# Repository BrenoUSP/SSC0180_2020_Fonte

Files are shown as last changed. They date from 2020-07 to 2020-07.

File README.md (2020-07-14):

# Fonte de Tensão
  Projeto de uma fonte de tensão ajustável de 3 a 12 Volts com capacidade de 100 mA, desenvolvido pelo aluno Breno Lívio Silva de Almeida (número USP 10276675).

## Objetivo
  Irá se partir da tensão da tomada (220V ou 127V) que vai ter que ser transformada de 127V/220V em Corrente Alternada (C.A.) em uma tensão adequada para alimentar nosso circuito. Isto é, de 3V-12V em Corrente Contínua (C.C.).

## Desenvolvimento do trabalho

### Componentes
|Nome|Quantidade|Especificações|Explicações|Preço Unitário|
|---|---|---|---|---|
| **Fonte de alimentação** |**1**| **Energia da tomada**| Fonte de energia 127V | ----------- | 
| **Interruptor** |**1**| **250 V e 3 A**| Apenas para ligar e desligar o circuito | [R$28,89](https://produto.mercadolivre.com.br/MLB-1300399738-boto-chave-gangorra-mini-interruptor-liga-desliga-on-off-10x15mm-kcd13-101-3a-250v-arduino-_JM) | 
|**Transformador**|**1**| **bivolt, 15 V e 500 mA**  | Esse transformador foi escolhido visando garantir  uma margem de erro confortável para quedas de tensão nos componentes, além de ser bivolt, podendo lidar com 127V/220V|[R$44,89](https://produto.mercadolivre.com.br/MLB-1305497792-transformador-1515v-2a-trafo-bivolt-_JM) |
|**Ponte Retificadora**|**1**| **1000 V e 2 A** | Responsável por fazer a conversão correta de C.A. para C.C. | [R$3,07](https://produto.mercadolivre.com.br/MLB-1151520283-ponte-retificadora-2w10-2a-1000v-lote-com-10-pecas-_JM)|
|**Capacitor**|**1**| **330 μf/35 V** | Usado para estabilização da tensão do circuito, armazenando energia. O valor se chegou demonstrado pelos cálculos que vão ser explicados em seguida |[R$2,62](https://produto.mercadolivre.com.br/MLB-1475685583-20x-capacitor-eletrolitico-330uf35v-smd-105-10x102mm-_JM)|
|**Diodo Zener**|**1**| **13 V - 0,5 W** | Regula a tensão a 13 V |[R$0,32](https://produto.mercadolivre.com.br/MLB-1395521239-diodo-zener-13v-05w-1n5243-lote-de-100-pecas-_JM)|
|**Transistor**|**1**| **2N2222A ¹** | Atenua a corrente e a tensão. Corrente máxima no coletor de 0.8 mA e tensão máxima do coletor 75 V, mais que o suficiente para trabalhar com 25 V de entrada  |[R$1,05](https://produto.mercadolivre.com.br/MLB-1222136291-20-pecas-transistor-npn-2n2222a-_JM) |
|**Resistência**|**2**| **5,6K Ω** | R1 utilizado para limitar a tensão no zener de modo que está fique na faixa de 13V e o R3 se adapta ao potenciômetro mantendo a tensão de 3V a 12V  |[R$1,08](https://produto.mercadolivre.com.br/MLB-1388075980-50un-resistor-1w-de-potencia-escolha-1-valor-ohmico-na-lista-_JM) 
|**Potenciômetro**|**1**| **10k Ω**  | Mantém a tensão da fonte entre 3 V e 12 V | [R$2,8](https://produto.mercadolivre.com.br/MLB-882483201-10x-potencimetro-10k-linear-com-eixo-l20-estriado-_JM)|

|**Preço total (com o frete)**|
|---|
|R$84,72|

### Cálculos

  Foi necessário realizar contas específicas se utilizando dos princípios da eletrônica para se obter os valores usados pelos componentes para se ter um circuito funcional. Primeiro deve-se calcular a tensão de pico primário, considerando a tensão de entrada sendo a fonte de alimentação de 127 V:

  <div align="center">
<p float="left">
  
</p>
</div>

  Em seguida calcula-se a tensão de pico secundário, levando-se o conta o ripple, na eletrônica é um valor residual e periódico obtido de uma fonte de tensão que, por sua vez, é alimentada por uma corrente alternada. Para isso busca-se um ripple de 10% ² da tensão de saída esperada de 25 V, ou seja, 2,5 V. Além disso, considera-se a tensão de um diodo de silício, em 0,65 V:

  <div align="center">
<p float="left">
  
</p>
</div>

  O período é dado por:

  <div align="center">
<p float="left">
  
</p>
</div>

  Com o período, encontra-se o tempo de carga:
  
  <div align="center">
<p float="left">
  
</p>
</div>

  Por fim, é possível encontrar a fórmula da capacitância ³, o que auxiliou a escolher um valor adequado para o **capacitor** de 330 µF, por ser acima do encontrado e por ser um valor comercial:
  
  <div align="center">
<p float="left">
  
</p>
</div>

### Vídeo-tutorial

  O vídeo a seguir descreve exatamente como o projeto foi criado, esclarecendo melhor como utilizar as ferramentas e softwares em questão.
  
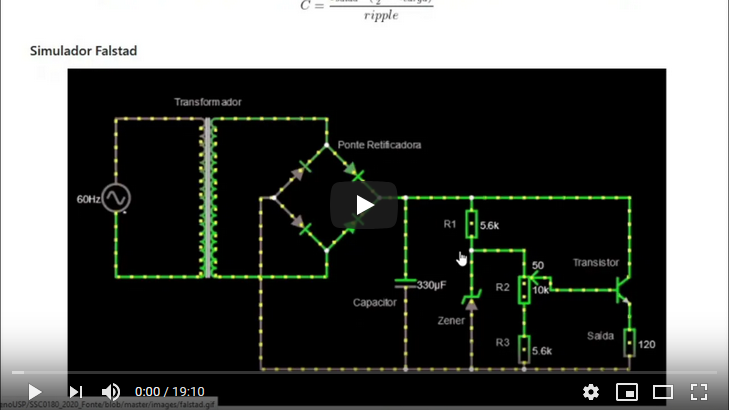
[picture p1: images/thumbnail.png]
Imagem da Thumbnail (https://youtu.be/79nIhM0iwAM)
  

### Simulador Falstad

<div align="center">
<p float="left">
  
</p>
</div>

  Falstad é um applet originalmente desenvolvido em Java, agora numa versão Javascript, feito para fazer simulações com circuitos. Você pode encontrar o repositório no GitHub [aqui](https://github.com/pfalstad/circuitjs1/).

  A simulação desse trabalho: [Link da simulação](http://tinyurl.com/y7hmerds)

### EAGLE

  Para o desenvolvimento de um esquemático e da PCB do circuito, foi utilizado do software EAGLE, que foi ensinado pelo professor sobre suas capacidades e instruções importantes para o desenvolvimento eficaz de circuitos como os esperados na disciplina.
  
#### Esquemático

  O projeto esquemático no EAGLE é análogo a uma "planta" de um circuito. Nele são ilustrados os componentes, valores e suas conexões no circuito.

<div align="center">
<p float="left">
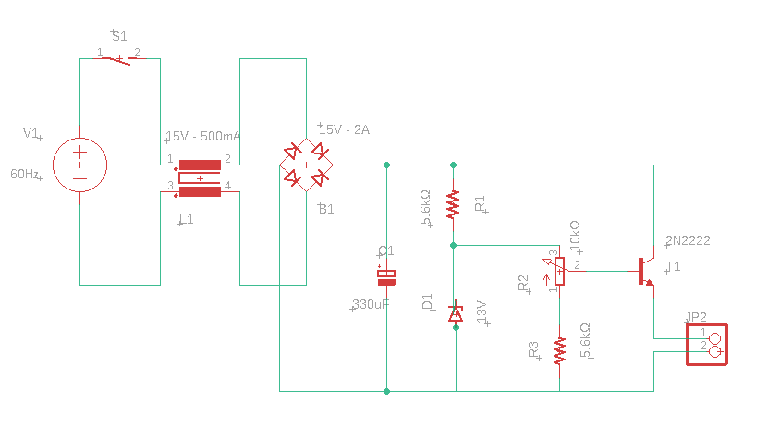
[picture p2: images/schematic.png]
  
</p>
</div>

#### PCB

  O PCB é uma placa dedicada a expressar as conexões de um determinado circuito, auxiliando numa instalação mais precisa e compacta de um circuito. Nota-se que para impressão desse circuito, a imagem deve estar como espelhada, sendo assim possível transcever o circuito diretamente na placa com alguma caneta ou análogo. Além disso, é necessário esclarecer que para um circuito em escala real, o transformador provavelmente ficaria fora da placa PCB.

<div align="center">
<p float="left">
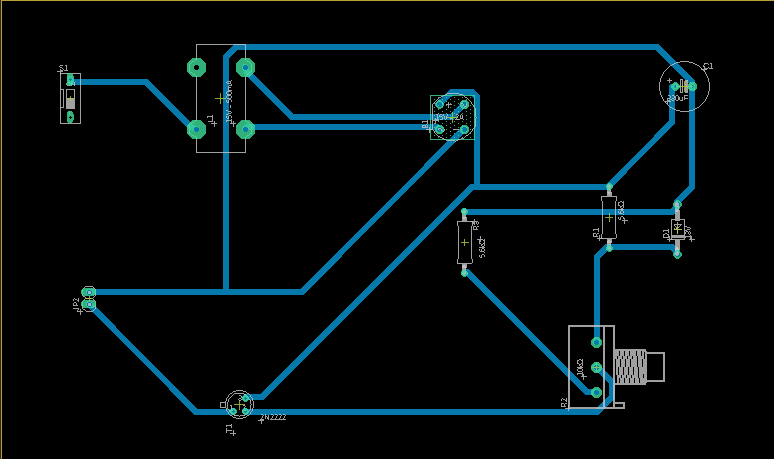
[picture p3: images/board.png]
  
</p>
</div>

### Bibliografia

¹ [Datasheet do transistor usado](https://www.onsemi.com/pub/Collateral/P2N2222A-D.PDF)

² [Valor adequado para o ripple](https://www.google.com/url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)

³ [Fórmula da capacitância mínima, da Texas Instruments](https://www.ti.com/lit/an/slta055/slta055.pdf)

Trabalho proposto pelo professor Eduardo Simões para a matéria de Eletrônica do Curso de Bacharelado em Ciências de Computação do Instituto de Ciências Matemáticas e de Computação (ICMC-USP).

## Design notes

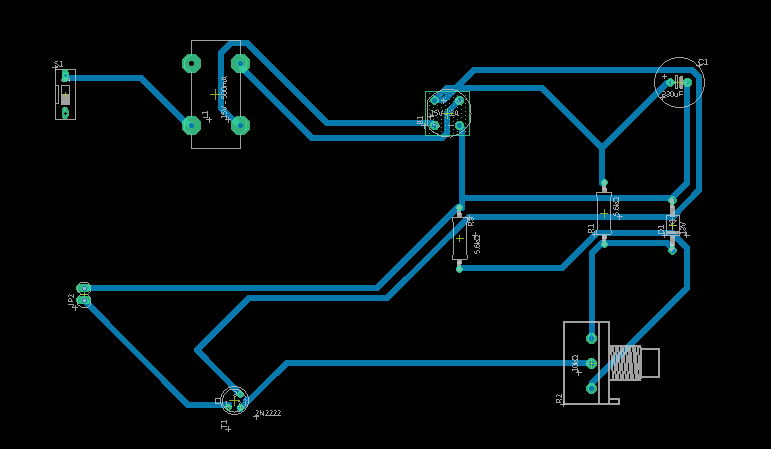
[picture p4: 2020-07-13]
images/pcb.png

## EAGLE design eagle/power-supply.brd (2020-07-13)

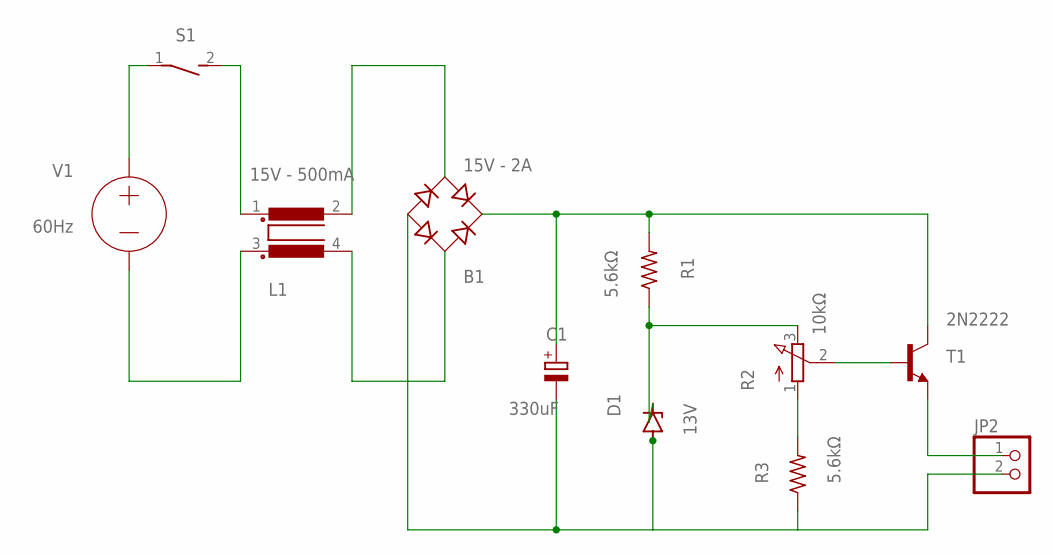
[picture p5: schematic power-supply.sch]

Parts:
B1: 15V - 2A; RB1A
C1: 330uF; E3,5-10
D1: 13V; DO41Z10
JP2: PINHD-1X2; 1X02
L1: 15V - 500mA; B2
R1, R3: 5.6kΩ; 0309/12
R2: 10kΩ; 3RP/1610N
S1: DS01E; DS-01
T1: 2N2222; TO18

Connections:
unnamed: R2.1 (A), R3.2
unnamed: B1.AC2, L1.2
unnamed: B1.AC1, L1.4
unnamed: D1.C, R1.1, R2.3 (E)
unnamed: B1.+, C1.+, R1.2, T1.3 (C)
unnamed: B1.-, C1.-, D1.A, JP2.2, R3.1
unnamed: JP2.1, T1.1 (E)
unnamed: L1.1, S1.2
unnamed: R2.2 (S), T1.2 (B)

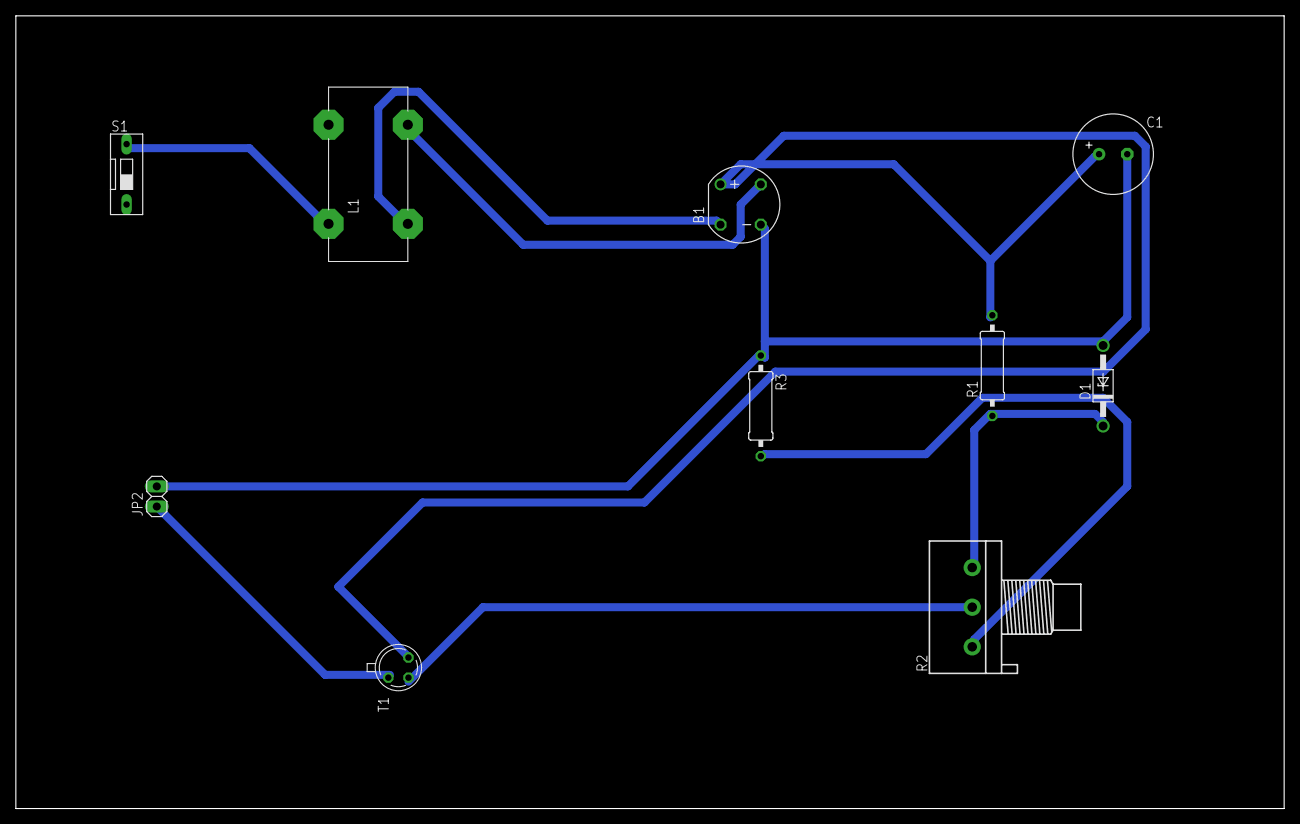
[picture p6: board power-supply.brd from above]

Board: 2 copper layers, 160.0 x 100.0 mm, 10 parts (0 on the bottom side), 9 nets.

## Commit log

2020-07-13 Falstad circuit animation gif
2020-07-13 Correção de símbolos e adição de mais links para a bibliografia
2020-07-13 Informações sobre esquemático e PCB
2020-07-13 Imagens esquemático e PCB
2020-07-13 Arquivos do EAGLE
    [power-supply.brd, power-supply.sch]
2020-07-14 Arquivo de thumbnail do vídeo
2020-07-14 Correção de erros no EAGLE
2020-07-14 Imagem da PCB atualizado com fios corretos
2020-07-14 Imagem do PCB atualizado
